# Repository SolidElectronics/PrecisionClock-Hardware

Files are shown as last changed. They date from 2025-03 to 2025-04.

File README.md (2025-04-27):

# PrecisionClock-Hardware
Alternate board designs for [mitxela/PrecisionClockMkII](https://github.com/mitxela/PrecisionClockMkII)

[0.56 inch x 18](/0.56%20inch%20x%2018) is a fully compatible version of the original design, but using the more readily available 0.56" displays.

[two row tenths v2](/two%20row%20tenths%20v2/) is a new design that requires modified firmware which you can get from [SolidElectronics/PrecisionClockMkII](https://github.com/SolidElectronics/PrecisionClockMkII).  That firmware supports both the original and new board versions (select using the #define statements).  The major changes included in this board are:

- Stacked date above time.  Date uses 0.56" LEDs and time uses 0.8" LEDs with 3mm LEDs for colons.

- USB-C power input, with footprints for mounting the connector on the side or the bottom.

- Dedicated holes for antenna mount, and I included STLs for the common ceramic antenna included with the GPS modules, and an SMA-mount if you'd prefer to use that.  I also added optional covers that can go over the colon indicators to make it look a bit more finished.

- Use surface-mount components wherever possible (not the AVR or MAX7219s because I already had the DIP versions)

- Switched non-segment indicators (colons and GMT/BST indicators) to use dedicated output pins on the MCU.  I found that driving anything other than the segments from the MAX7219 caused ghosting on the associated digits, and there wasn't a way to reduce the LED brightness that worked.

- Implemented digital brightness control.  The analog brightness control was great in theory but I couldn't get it to drive the LEDs at a level I was happy with, it would either be too bright or they'd go out entirely in a dark environment.  This probably could have been resolved by picking the correct transistors, LDR, and resistor values, but it was too much of a pain to re-solder them every time.

  Some concessions had to be made here due to the hardware limitations of the ATTiny2313, there is no ADC and only one available PWM output.  The LDR now uses the analog comparator to switch beteen high and low brightness, not a smooth gradient.  The non-segment indicators are PWM-driven through a 74AHCT125 so their brightness can be set independently from the main display, and the main display now uses the built-in dimming function from the MAX7219.  All of the parameters are tunable in the firmware, and there are potentiometers on the back to set the dimming switchover point and the overall date and time brightness levels.

It took a lot more work than I expected to get it to this point, and it was probably the most trace-dense board I've made, but overall I'm happy with how it turned out and it's now a permanent fixture in my office.

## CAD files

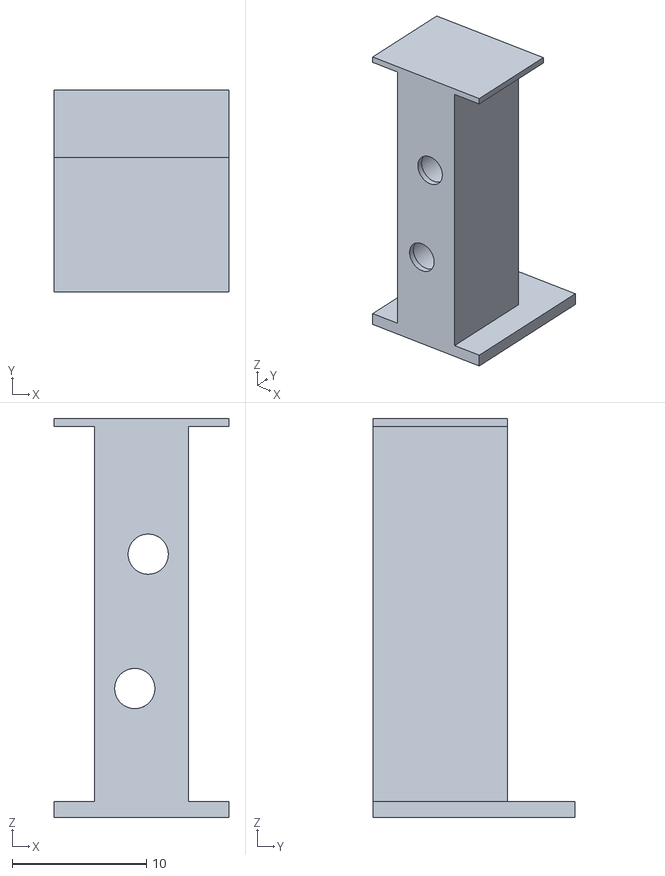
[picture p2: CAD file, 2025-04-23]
two row tenths v2/3D Print/Clock colon sleeve hole.stl
13.0 x 15.0 x 29.7

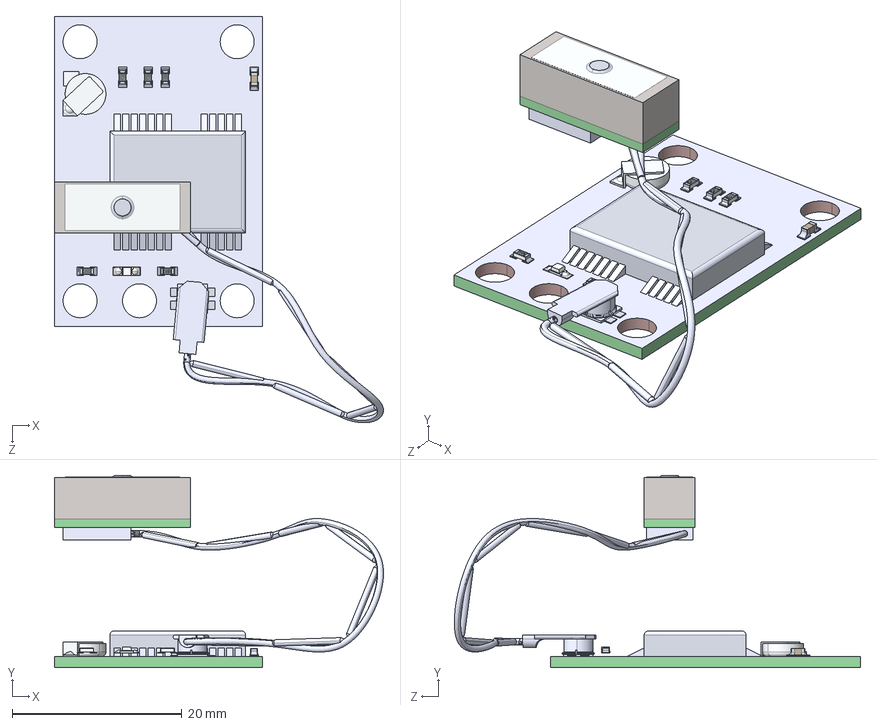
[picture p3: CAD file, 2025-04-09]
two row tenths v2/3d_models/ublox NEO-6M.STEP
38.7 x 22.6 x 47.9 mm
GPS_pcb
GPS_cap
GPS_res221 x 2
GPS_res472 x 2
GPS_battery
GPS_res100
GPS_led
GPS_connector
Antenna_connector
Antenna
Rod x 7
cable

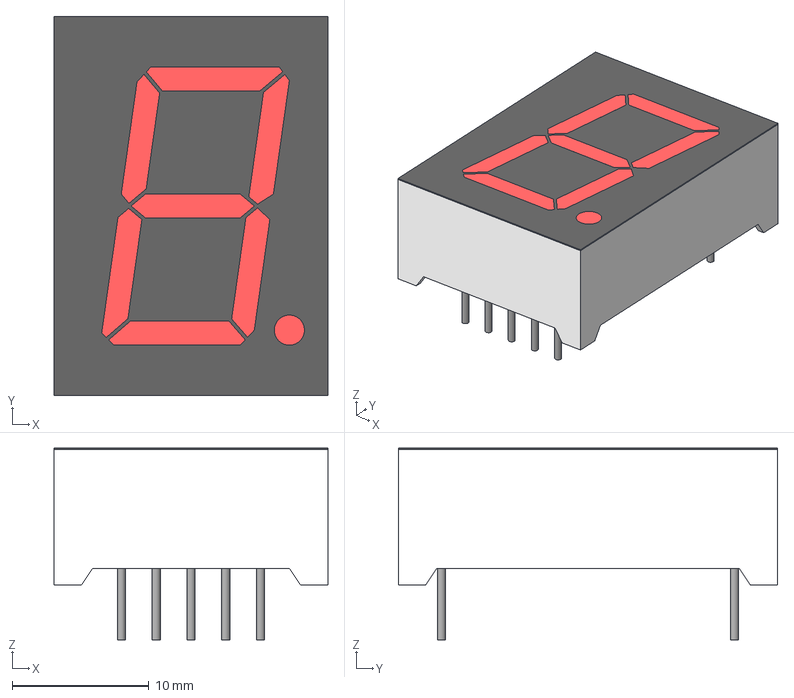
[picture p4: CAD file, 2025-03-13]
two row tenths v2/3d_models/7 seg 0,8 inch.step
20.0 x 27.7 x 14.0 mm

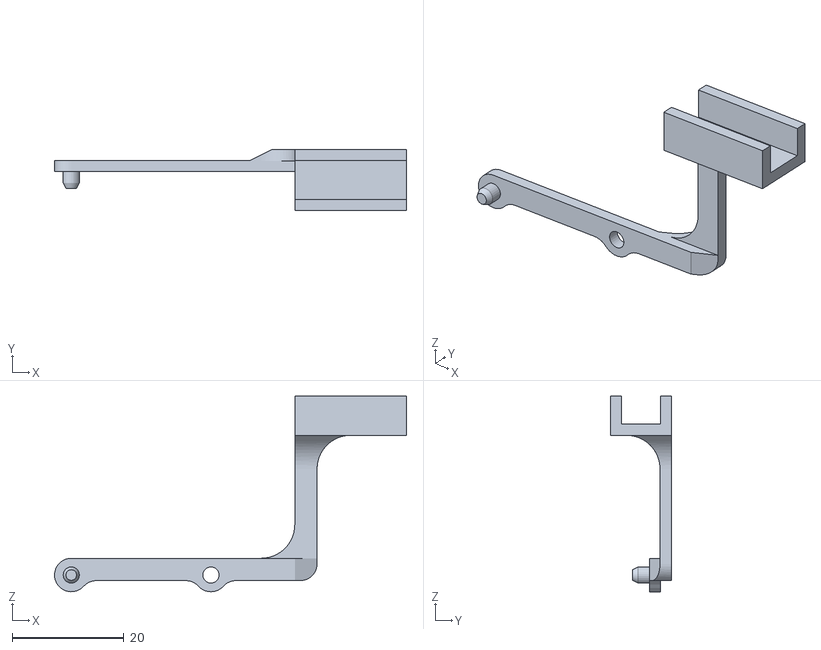
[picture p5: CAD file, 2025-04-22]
two row tenths v2/3D Print/Clock ceramic antenna mount.stl
63.0 x 11.0 x 35.0

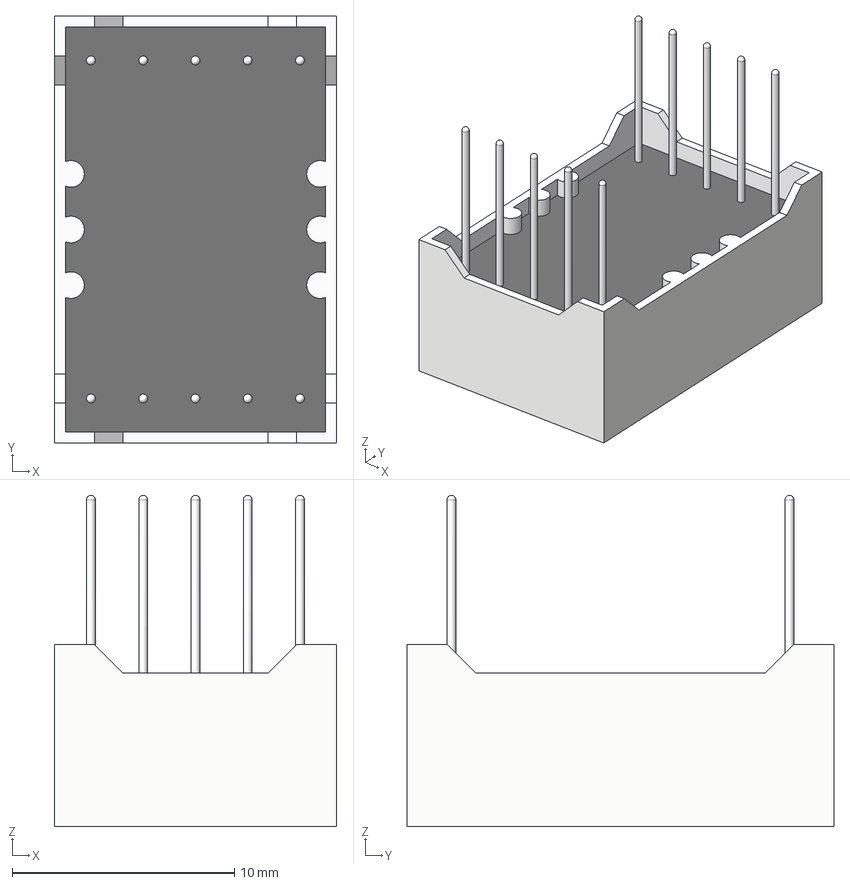
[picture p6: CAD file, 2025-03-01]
two row tenths v2/3d_models/7 Segment Anzeige_.step
12.7 x 19.2 x 14.9 mm

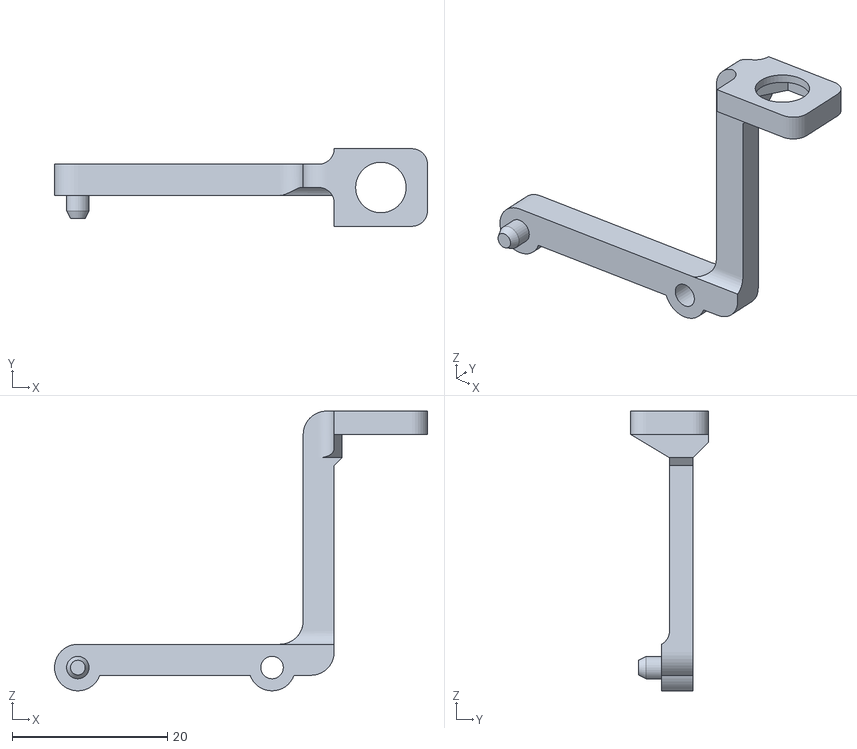
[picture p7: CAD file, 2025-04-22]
two row tenths v2/3D Print/Clock SMA antenna mount.stl
48.0 x 10.0 x 36.0

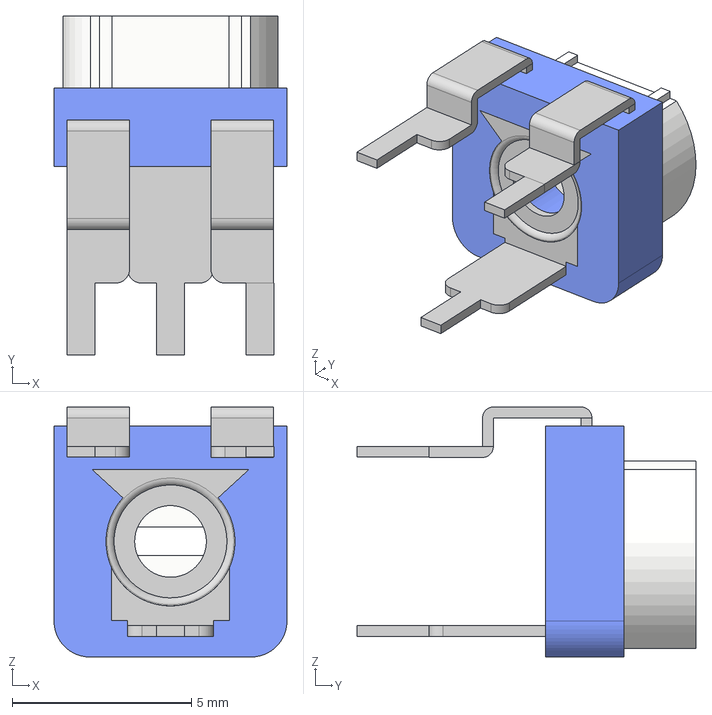
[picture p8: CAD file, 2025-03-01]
two row tenths v2/3d_models/Trimpot Horiz 5mm.step
6.50 x 9.45 x 6.97 mm

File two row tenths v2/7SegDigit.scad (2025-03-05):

w = 23.98;
h = 34;
d = 10.55;

t = 0.58;
u= d-8.1+1.55;

difference(){

    cube( [w,h,d] );

    //translate([0,0,11]) scale([w/211,h/299,-0.01]) %surface("7SegDigit-300.png");
    

    translate([21.2,5.9,10.4])
    scale([1.25,1.25,1])
    cylinder($fn=20);
    
    translate([0,0,10.4])
    linear_extrude(height=1)
    scale(0.1) {
        polygon([[47,42],[151,42],[160,50],[145,67],[62,67],[41,50]]);
        
        polygon([[37,54],[31,62],[50,166],[64,166],[73,153],[58,71]]);
        
        polygon([[164,54],[150,70],[164,152],[180,166],[192,166],[173,62]]);
        
        polygon([[76,156],[162,156],[175,169],[166,182],[82,182],[68,169]]);
        
        polygon([[51,172],[64,172],[79,186],[94,268],[79,284],[70,276]]);
        
        polygon([[180,171],[193,171],[213,276],[206,283],[185,266],[170,185]]);

        polygon([[97,271],[182,271],[202,288],[196,296],[93,297],[84,288]]);
        
    }
    
    translate([t,t,0])
    cube([w-2*t,h-2*t,u]);
    
    cutout1();
    cutout2();
}



module cutout1() {
    wt=17.7;
    wb=19.82;
    wc=(wb-wt)/2;
    wd=d-8.1;

    we = (w-wb)/2;
    
    
    translate([we,80,0])
    rotate([90,0,0])
    linear_extrude() polygon([[0,0],[wb,0],[wt+wc,wd],[wc,wd]]);
}

module cutout2() {
    wt=27.6;
    wb=29.55;
    wc=(wb-wt)/2;
    wd=d-8.1;

    we = (w-wb)/2;
    
    
    translate([-10,-we,0])
    rotate([90,0,90])
    linear_extrude() polygon([[0,0],[wb,0],[wt+wc,wd],[wc,wd]]);
}


pinr=0.48/2;

module pin(x,y){
    translate([x,y,u-8])

    cylinder(r=pinr,h=8,$fn=10);
}


for (i=[0:4])
    pin(6.75 -pinr + i*2.54, 2.1-pinr);


for (i=[0:4])
    pin( 6.85 -pinr + i*2.54, h-(2.1-pinr));

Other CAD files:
two row tenths v2/3D Print/Clock colon sleeve solid.stl

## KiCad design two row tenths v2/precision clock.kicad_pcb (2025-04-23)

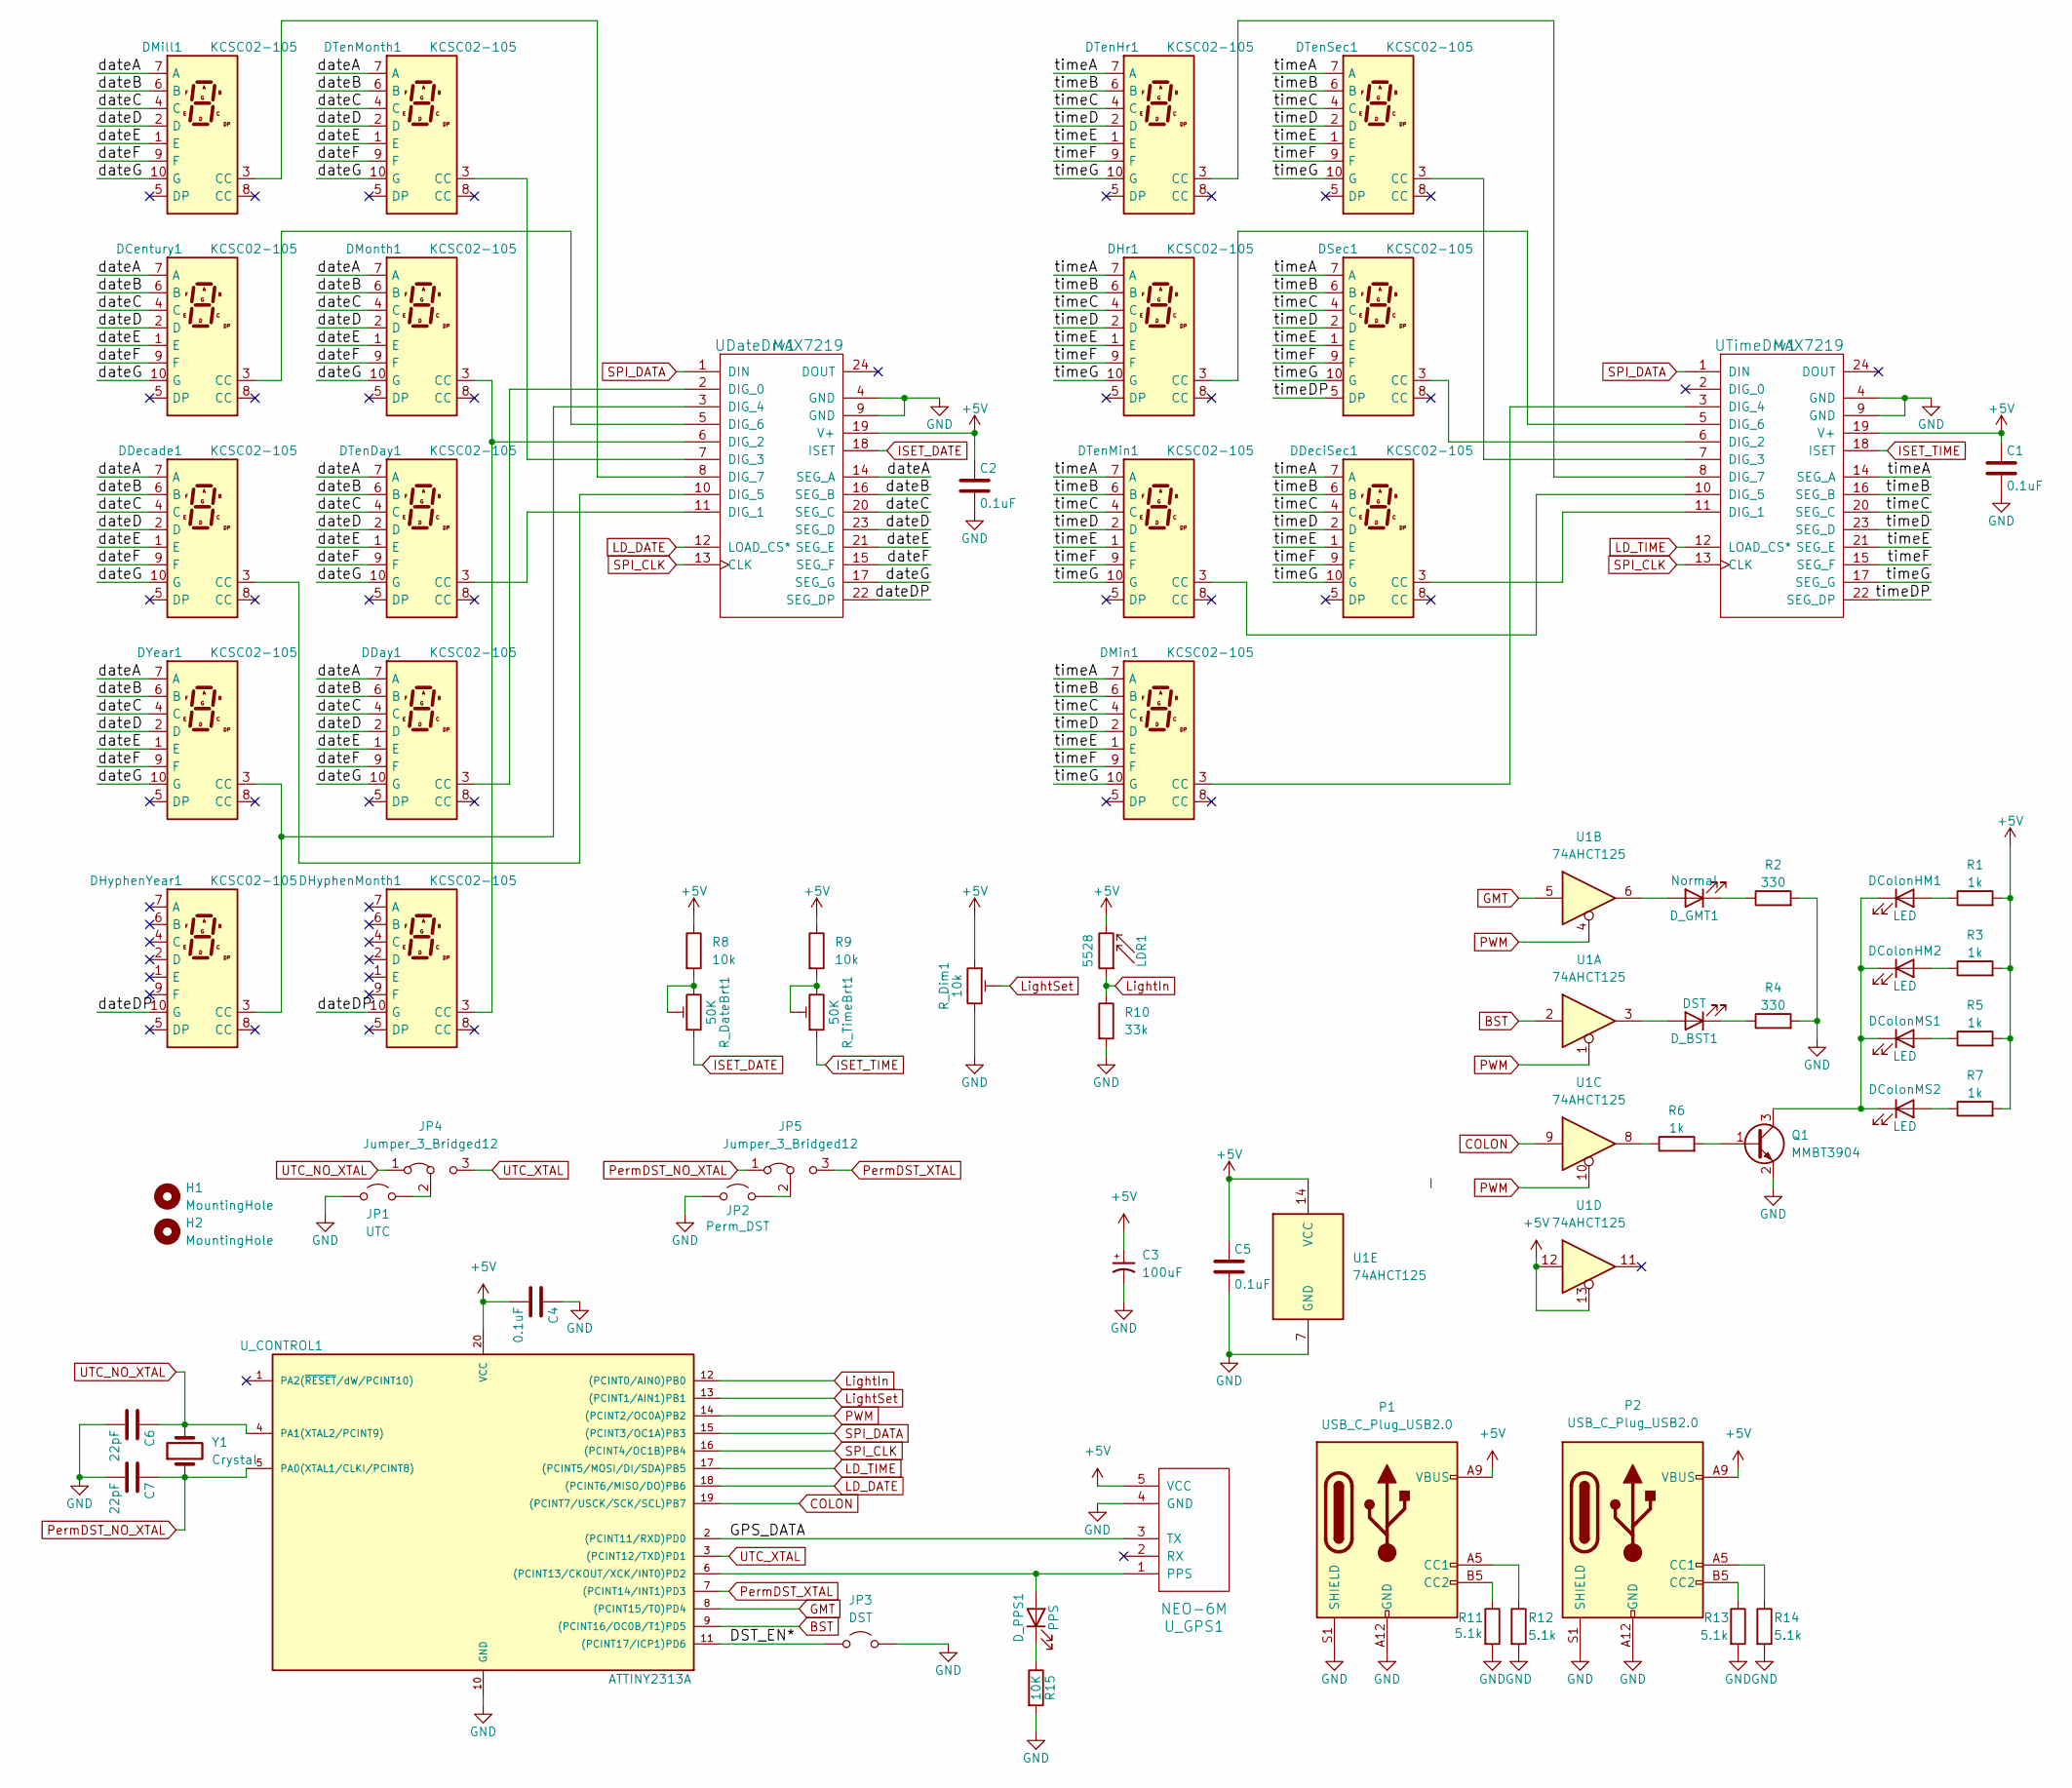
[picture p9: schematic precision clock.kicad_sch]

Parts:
C1, C2, C4, C5: 0.1uF; C_1206_3216Metric
C3: 100uF; CP_Radial_D6.3mm_P2.50mm
C6, C7: 22pF; C_1206_3216Metric
DCentury1: KCSC02-105; 7seg0.56CC
DColonHM1, DColonHM2: LED; LED_D5.0mm
DColonMS1, DColonMS2: LED; LED_D5.0mm
DDay1: KCSC02-105; 7seg0.56CC
DDecade1: KCSC02-105; 7seg0.56CC
DDeciSec1: KCSC02-105; 7seg0.8CC
DHr1: KCSC02-105; 7seg0.8CC
DHyphenMonth1: KCSC02-105; 7seg0.56CC
DHyphenYear1: KCSC02-105; 7seg0.56CC
DMill1: KCSC02-105; 7seg0.56CC
DMin1: KCSC02-105; 7seg0.8CC
DMonth1: KCSC02-105; 7seg0.56CC
DSec1: KCSC02-105; 7seg0.8CC
DTenDay1: KCSC02-105; 7seg0.56CC
DTenHr1: KCSC02-105; 7seg0.8CC
DTenMin1: KCSC02-105; 7seg0.8CC
DTenMonth1: KCSC02-105; 7seg0.56CC
DTenSec1: KCSC02-105; 7seg0.8CC
DYear1: KCSC02-105; 7seg0.56CC
D_BST1: DST; LED_1206_3216Metric
D_GMT1: Normal; LED_1206_3216Metric
D_PPS1: PPS; LED_1206_3216Metric
H1, H2: MountingHole; MountingHole_3.2mm_M3
JP1: UTC; PinHeader_1x02_P2.54mm_Vertical
JP2: Perm_DST; PinHeader_1x02_P2.54mm_Vertical
JP3: DST; PinHeader_1x02_P2.54mm_Vertical
JP4, JP5: Jumper_3_Bridged12; SolderJumper-3_P1.3mm_Bridged12_Pad1.0x1.5mm
LDR1: 5528; R_LDR_4.9x4.2mm_P2.54mm_Vertical
P1, P2: USB_C_Plug_USB2.0; USB_C_Receptacle_HRO_TYPE-C-31-M-17
Q1: MMBT3904; SOT-23
R1, R3, R5, R6, R7: 1k; R_1206_3216Metric
R2, R4: 330; R_1206_3216Metric
R8, R9: 10k; R_1206_3216Metric
R10: 33k; R_1206_3216Metric
R11, R12, R13, R14: 5.1k; R_1206_3216Metric
R15: 10K; R_1206_3216Metric
R_DateBrt1: 50K; Potentiometer_Piher_PT-6-V_Vertical
R_Dim1: 10k; Potentiometer_Piher_PT-6-V_Vertical
R_TimeBrt1: 50K; Potentiometer_Piher_PT-6-V_Vertical
U1: 74AHCT125; SOIC-14_3.9x8.7mm_P1.27mm
UDateDrv1: MAX7219; DIP-24_W7.62mm
UTimeDrv1: MAX7219; DIP-24_W7.62mm
U_CONTROL1: ATTINY2313A; DIP-20_W7.62mm
U_GPS1: NEO-6M; ublox_GPS
Y1: Crystal; Crystal_SMD_HC49-SD

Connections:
+5V: C1.1, C2.1, C3.1, C4.2, C5.1, LDR1.2, P1.A9 (VBUS), P1.B9 (VBUS), P2.A9 (VBUS), P2.B9 (VBUS), R1.2, R3.2, R5.2, R7.2, R8.1, R9.1, R_Dim1.1, U1.12, U1.13, U1.14 (VCC), UDateDrv1.19 (V+), UTimeDrv1.19 (V+), U_CONTROL1.20 (VCC), U_GPS1.5 (VCC)
/DST_EN*: JP3.1 (A), U_CONTROL1.11 ((PCINT17/ICP1)PD6)
/GPS_DATA: U_CONTROL1.2 ((PCINT11/RXD)PD0), U_GPS1.3 (TX)
/dateA: DCentury1.7 (A), DDay1.7 (A), DDecade1.7 (A), DMill1.7 (A), DMonth1.7 (A), DTenDay1.7 (A), DTenMonth1.7 (A), DYear1.7 (A), UDateDrv1.14 (SEG_A)
/dateB: DCentury1.6 (B), DDay1.6 (B), DDecade1.6 (B), DMill1.6 (B), DMonth1.6 (B), DTenDay1.6 (B), DTenMonth1.6 (B), DYear1.6 (B), UDateDrv1.16 (SEG_B)
/dateC: DCentury1.4 (C), DDay1.4 (C), DDecade1.4 (C), DMill1.4 (C), DMonth1.4 (C), DTenDay1.4 (C), DTenMonth1.4 (C), DYear1.4 (C), UDateDrv1.20 (SEG_C)
/dateD: DCentury1.2 (D), DDay1.2 (D), DDecade1.2 (D), DMill1.2 (D), DMonth1.2 (D), DTenDay1.2 (D), DTenMonth1.2 (D), DYear1.2 (D), UDateDrv1.23 (SEG_D)
/dateDP: DHyphenMonth1.10 (G), DHyphenYear1.10 (G), UDateDrv1.22 (SEG_DP)
/dateE: DCentury1.1 (E), DDay1.1 (E), DDecade1.1 (E), DMill1.1 (E), DMonth1.1 (E), DTenDay1.1 (E), DTenMonth1.1 (E), DYear1.1 (E), UDateDrv1.21 (SEG_E)
/dateF: DCentury1.9 (F), DDay1.9 (F), DDecade1.9 (F), DMill1.9 (F), DMonth1.9 (F), DTenDay1.9 (F), DTenMonth1.9 (F), DYear1.9 (F), UDateDrv1.15 (SEG_F)
/dateG: DCentury1.10 (G), DDay1.10 (G), DDecade1.10 (G), DMill1.10 (G), DMonth1.10 (G), DTenDay1.10 (G), DTenMonth1.10 (G), DYear1.10 (G), UDateDrv1.17 (SEG_G)
/timeA: DDeciSec1.7 (A), DHr1.7 (A), DMin1.7 (A), DSec1.7 (A), DTenHr1.7 (A), DTenMin1.7 (A), DTenSec1.7 (A), UTimeDrv1.14 (SEG_A)
/timeB: DDeciSec1.6 (B), DHr1.6 (B), DMin1.6 (B), DSec1.6 (B), DTenHr1.6 (B), DTenMin1.6 (B), DTenSec1.6 (B), UTimeDrv1.16 (SEG_B)
/timeC: DDeciSec1.4 (C), DHr1.4 (C), DMin1.4 (C), DSec1.4 (C), DTenHr1.4 (C), DTenMin1.4 (C), DTenSec1.4 (C), UTimeDrv1.20 (SEG_C)
/timeD: DDeciSec1.2 (D), DHr1.2 (D), DMin1.2 (D), DSec1.2 (D), DTenHr1.2 (D), DTenMin1.2 (D), DTenSec1.2 (D), UTimeDrv1.23 (SEG_D)
/timeDP: DSec1.5 (DP), UTimeDrv1.22 (SEG_DP)
/timeE: DDeciSec1.1 (E), DHr1.1 (E), DMin1.1 (E), DSec1.1 (E), DTenHr1.1 (E), DTenMin1.1 (E), DTenSec1.1 (E), UTimeDrv1.21 (SEG_E)
/timeF: DDeciSec1.9 (F), DHr1.9 (F), DMin1.9 (F), DSec1.9 (F), DTenHr1.9 (F), DTenMin1.9 (F), DTenSec1.9 (F), UTimeDrv1.15 (SEG_F)
/timeG: DDeciSec1.10 (G), DHr1.10 (G), DMin1.10 (G), DSec1.10 (G), DTenHr1.10 (G), DTenMin1.10 (G), DTenSec1.10 (G), UTimeDrv1.17 (SEG_G)
BST: U1.2, U_CONTROL1.9 ((PCINT16/OC0B/T1)PD5)
COLON: U1.9, U_CONTROL1.19 ((PCINT7/USCK/SCK/SCL)PB7)
GMT: U1.5, U_CONTROL1.8 ((PCINT15/T0)PD4)
GND: C1.2, C2.2, C3.2, C4.1, C5.2, C6.2, C7.2, JP1.2 (B), JP2.2 (B), JP3.2 (B), P1.A12 (GND), P1.B12 (GND), P1.S1 (SHIELD), P2.A12 (GND), P2.B12 (GND), P2.S1 (SHIELD), Q1.2 (E), R2.2, R4.2, R10.2, R11.2, R12.2, R13.2, R14.2, R15.2, R_Dim1.3, U1.7 (GND), UDateDrv1.4 (GND), UDateDrv1.9 (GND), UTimeDrv1.4 (GND), UTimeDrv1.9 (GND), U_CONTROL1.10 (GND), U_GPS1.4 (GND)
ISET_DATE: R_DateBrt1.1, UDateDrv1.18 (ISET)
ISET_TIME: R_TimeBrt1.1, UTimeDrv1.18 (ISET)
LD_DATE: UDateDrv1.12 (LOAD_CS*), U_CONTROL1.18 ((PCINT6/MISO/DO)PB6)
LD_TIME: UTimeDrv1.12 (LOAD_CS*), U_CONTROL1.17 ((PCINT5/MOSI/DI/SDA)PB5)
LightIn: LDR1.1, R10.1, U_CONTROL1.12 ((PCINT0/AIN0)PB0)
LightSet: R_Dim1.2, U_CONTROL1.13 ((PCINT1/AIN1)PB1)
unnamed: DColonHM1.2 (A), R1.1
unnamed: DColonHM1.1 (K), DColonHM2.1 (K), DColonMS1.1 (K), DColonMS2.1 (K), Q1.3 (C)
unnamed: DColonHM2.2 (A), R3.1
unnamed: DColonMS1.2 (A), R5.1
unnamed: DColonMS2.2 (A), R7.1
unnamed: D_BST1.2 (A), U1.3
unnamed: D_BST1.1 (K), R4.1
unnamed: D_GMT1.2 (A), U1.6
unnamed: D_GMT1.1 (K), R2.1
unnamed: D_PPS1.2 (A), U_CONTROL1.6 ((PCINT13/CKOUT/XCK/INT0)PD2), U_GPS1.1 (PPS)
unnamed: D_PPS1.1 (K), R15.1
unnamed: JP1.1 (A), JP4.2 (C)
unnamed: JP2.1 (A), JP5.2 (C)
unnamed: P1.A5 (CC1), R12.1
unnamed: P1.B5 (CC2), R11.1
unnamed: P2.A5 (CC1), R14.1
unnamed: P2.B5 (CC2), R13.1
unnamed: Q1.1 (B), R6.2
unnamed: R6.1, U1.8
unnamed: R8.2, R_DateBrt1.2, R_DateBrt1.3
unnamed: R9.2, R_TimeBrt1.2, R_TimeBrt1.3
unnamed: DDay1.3 (CC), UDateDrv1.2 (DIG_0)
unnamed: DTenDay1.3 (CC), UDateDrv1.11 (DIG_1)
unnamed: DHyphenMonth1.3 (CC), DMonth1.3 (CC), UDateDrv1.6 (DIG_2)
unnamed: DTenMonth1.3 (CC), UDateDrv1.7 (DIG_3)
unnamed: DHyphenYear1.3 (CC), DYear1.3 (CC), UDateDrv1.3 (DIG_4)
unnamed: DDecade1.3 (CC), UDateDrv1.10 (DIG_5)
unnamed: DCentury1.3 (CC), UDateDrv1.5 (DIG_6)
unnamed: DMill1.3 (CC), UDateDrv1.8 (DIG_7)
unnamed: DDeciSec1.3 (CC), UTimeDrv1.11 (DIG_1)
unnamed: DSec1.3 (CC), UTimeDrv1.6 (DIG_2)
unnamed: DTenSec1.3 (CC), UTimeDrv1.7 (DIG_3)
unnamed: DMin1.3 (CC), UTimeDrv1.3 (DIG_4)
unnamed: DTenMin1.3 (CC), UTimeDrv1.10 (DIG_5)
unnamed: DHr1.3 (CC), UTimeDrv1.5 (DIG_6)
unnamed: DTenHr1.3 (CC), UTimeDrv1.8 (DIG_7)
PWM: U1.1, U1.4, U1.10, U_CONTROL1.14 ((PCINT2/OC0A)PB2)
PermDST_NO_XTAL: C7.1, JP5.1 (A), U_CONTROL1.5 (PA0(XTAL1/CLKI/PCINT8)), Y1.1
PermDST_XTAL: JP5.3 (B), U_CONTROL1.7 ((PCINT14/INT1)PD3)
SPI_CLK: UDateDrv1.13 (CLK), UTimeDrv1.13 (CLK), U_CONTROL1.16 ((PCINT4/OC1B)PB4)
SPI_DATA: UDateDrv1.1 (DIN), UTimeDrv1.1 (DIN), U_CONTROL1.15 ((PCINT3/OC1A)PB3)
UTC_NO_XTAL: C6.1, JP4.1 (A), U_CONTROL1.4 (PA1(XTAL2/PCINT9)), Y1.2
UTC_XTAL: JP4.3 (B), U_CONTROL1.3 ((PCINT12/TXD)PD1)

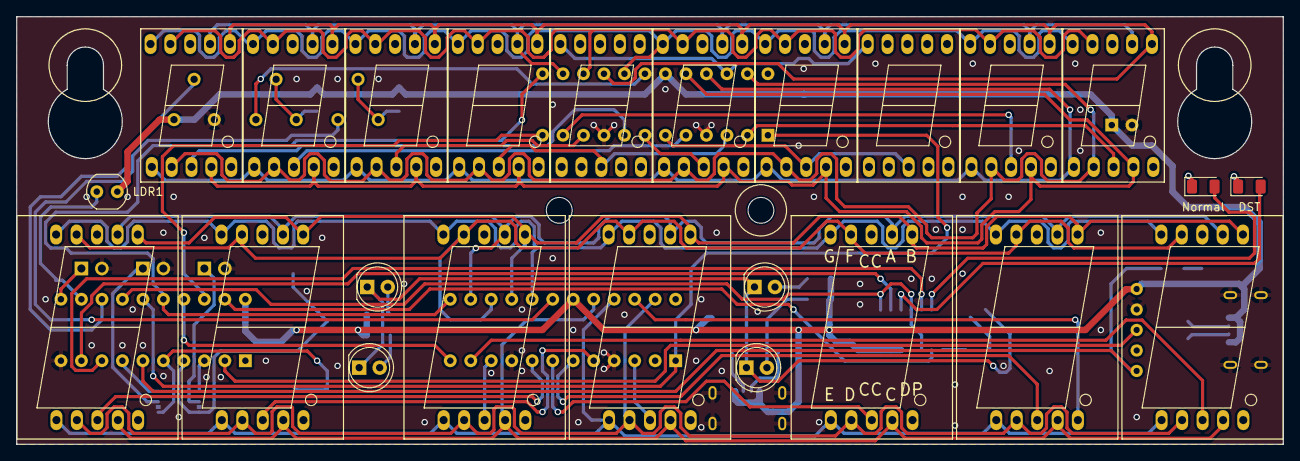
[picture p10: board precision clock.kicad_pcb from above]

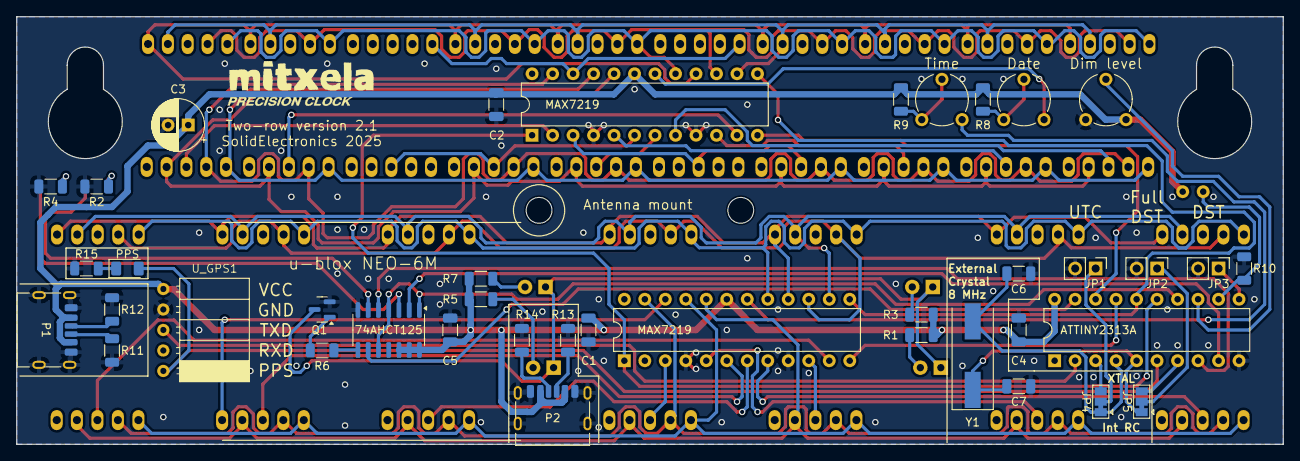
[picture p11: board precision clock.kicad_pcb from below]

Board: 2 copper layers, 157.0 x 53.0 mm, 66 parts (40 on the bottom side), 72 nets.

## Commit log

2025-03-01 0.56" version v1
    [7 Segment Anzeige_.step, Trimpot Horiz 5mm.step, precision clock.kicad_pcb]
2025-03-02 Add new schematic format
    [precision clock.kicad_sch, precision clock.sch]
2025-03-02 Cleanup rescue files
    [precision clock-2018-07-31-22-00-32.sch, precision clock-2018-08-07-20-23-16.sch]
2025-03-02 Add jumpers for permaDST and UTC
    [precision clock.kicad_pcb, precision clock.kicad_sch]
2025-03-05 Move 0.56" into new folder
    [7 Segment Anzeige_.step, 7SegDigit.scad, BarrelJack.scad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]
2025-03-05 Create new layout for two rows, 1" time and 0.56" date
    [7 Segment Anzeige_.step, 7SegDigit.scad, BarrelJack.scad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]
2025-03-05 Cleanup base dir
    [7 Segment Anzeige_.step, 7SegDigit.scad, BarrelJack.scad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]
2025-03-13 Rebuild two-row for 0.8" segments and improvements from prototype (1.0" are very difficult to source)
    [7 seg 0,8 inch.step, precision clock.kicad_pcb, precision clock.kicad_sch]
2025-03-17 Remove extra resistors, add second USB port location, cleanup trace routing
    [precision clock.kicad_pcb, precision clock.kicad_sch]
2025-03-19 Add wire to seconds decimal point
    [precision clock.kicad_pcb, precision clock.kicad_sch]
2025-03-22 Fixed USB-C pinout and CC resistors
    [precision clock.kicad_pcb, precision clock.kicad_sch]
2025-03-23 Fix reference designators
    [precision clock.kicad_pcb, precision clock.kicad_sch]
2025-03-23 Add new two-row version including tenth second digit
    [7 Segment Anzeige_.step, 7 seg 0,8 inch.step, 7SegDigit.scad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]
2025-03-23 Move over bottom USB connector
    [precision clock.kicad_pcb]
2025-04-03 Add resistor so we don't short Q2
    [precision clock.kicad_pcb, precision clock.kicad_sch]
2025-04-04 More resistors for brightness tuning
    [precision clock.kicad_pcb, precision clock.kicad_sch]
2025-04-07 Add new version with MCU driven colons and digital dimming, fixing problems found in version 1.
    [7 Segment Anzeige_.step, 7 seg 0,8 inch.step, 7SegDigit.scad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]
2025-04-09 Add 74AHCT125 as PWM driver
    [precision clock.kicad_pcb, precision clock.kicad_sch]
2025-04-09 Add optional crystal
    [precision clock.kicad_pcb, precision clock.kicad_sch]
2025-04-09 Add GPS model, sending to production.
    [precision clock.kicad_pcb, precision clock.kicad_sch, ublox NEO-6M.STEP]
2025-04-22 Fix LED polarity, add STLs for antenna mounts
    [Clock SMA antenna mount.stl, Clock ceramic antenna mount.stl, precision clock.kicad_pcb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]
2025-04-23 Cleanup old projects
    [7 Segment Anzeige_.step, 7 seg 0,8 inch.step, 7SegDigit.scad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]
